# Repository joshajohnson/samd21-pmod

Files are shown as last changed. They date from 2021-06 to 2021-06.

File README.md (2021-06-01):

# Template Hardware Project

## Generate production files
`make`

* generates zipped gerbers, BOM, and iBOM PnP file

## Init Repo
* Due to GitHub template not supporting submodules yet, the below process is required upon first use to configure.
```
git clone git@github.com:joshajohnson/hardware-template.git
mv hardware-template project-name
cd project-name
make init
```

* Configure new git repo

## Begin a new project / board revision
`make new NAME="project-name" VERSION="version" DESIGNER="Your Name"`

* `NAME` is the file name of project and is required, no spaces allowed
* `VERSION` is optional and defaults to `0.1`, must be unique
* `DESIGNER` is optional and defaults to `Josh Johnson`

## Generate gerbers
`make gerb` 

* requires python3 and a small number of dependencies

## Generate BOM
`make bom`

* utilises custom BOM format found in `scripts/josh_bom.py`
* requires dependancy to be installed to global scope `pip3 install kicad_netlist_reader`

## Generate InteractiveHTMLBom
`make pnp`

* requires [InteractiveHTMLBom](https://github.com/openscopeproject/InteractiveHtmlBom) to be installed in `~/local/share/kicad/5.99/scripting/plugins`
* generates ibom according to settings from pcbnew

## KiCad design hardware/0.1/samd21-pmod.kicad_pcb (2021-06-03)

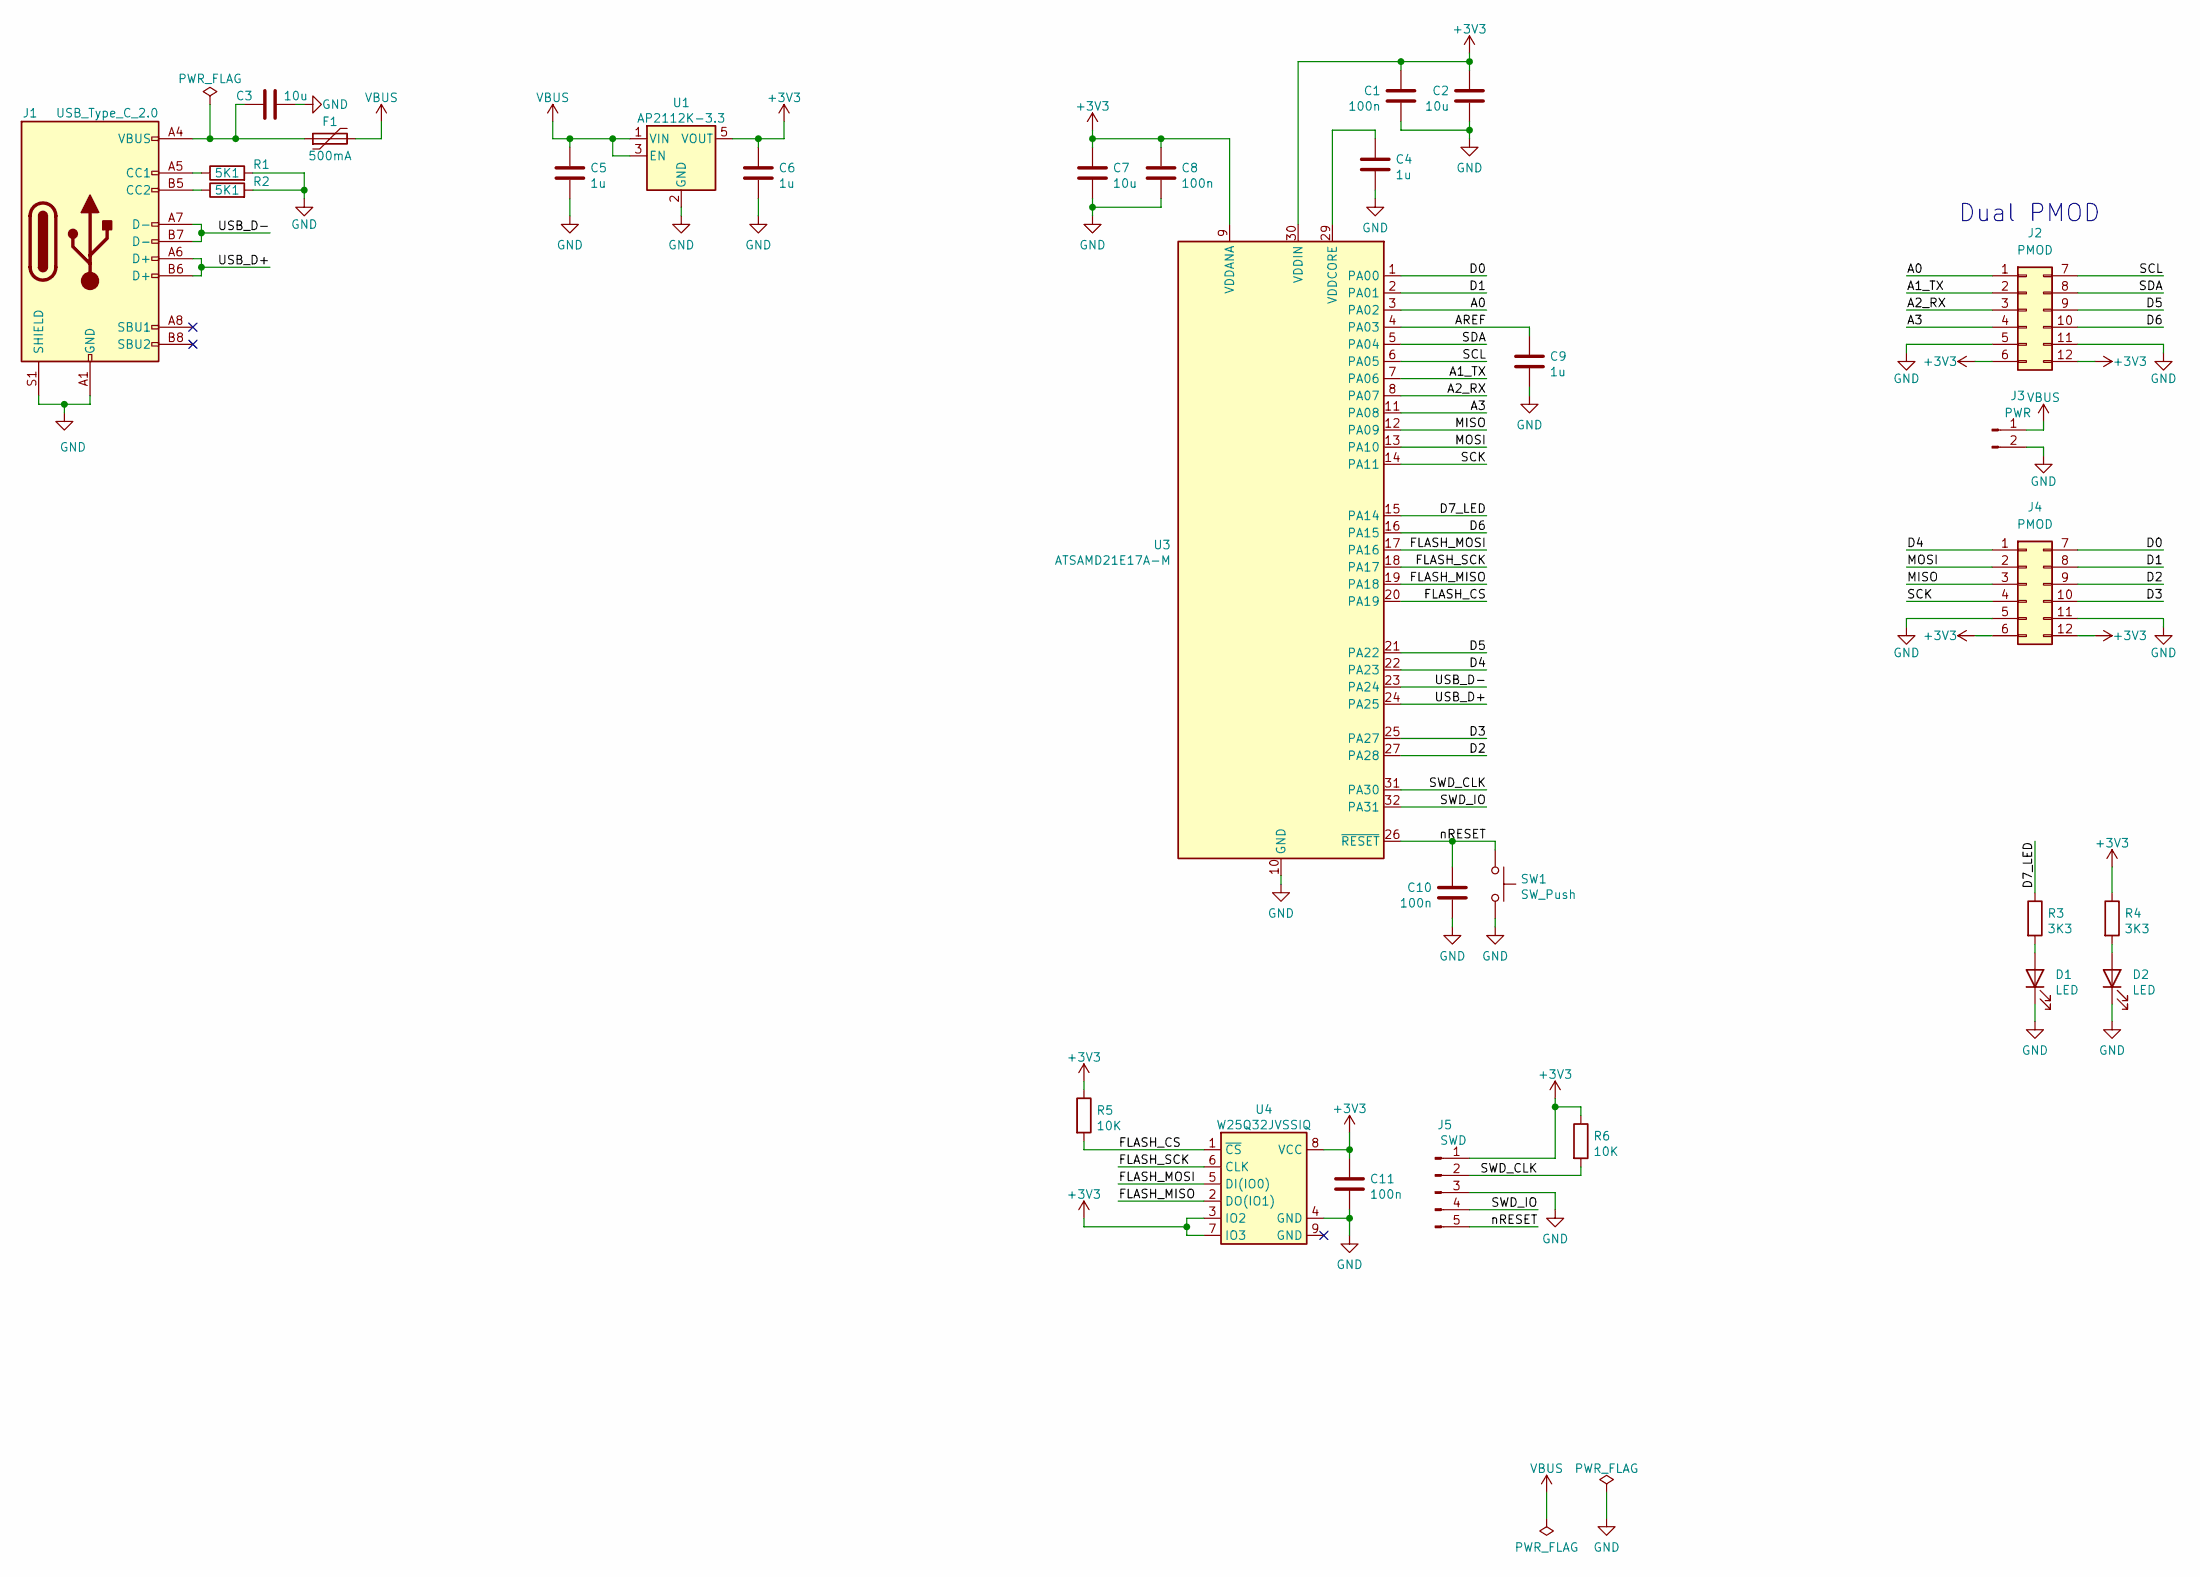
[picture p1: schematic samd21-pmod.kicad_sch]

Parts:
C1, C8, C10, C11: 100n; C_0603_1608Metric
C2, C3, C7: 10u; C_0603_1608Metric
C4, C5, C6, C9: 1u; C_0603_1608Metric
D1, D2: LED; LED_0603_1608Metric
F1: 500mA; Fuse_0603_1608Metric
J1: USB_Type_C_2.0; USB_C_Receptacle_HRO_TYPE-C-31-M-12
J2, J4: PMOD; PMOD_HOST
J3: PWR; PinSocket_1x02_P2.54mm_Vertical
J5: SWD; 5_PIN_THT_Staggered
R1, R2: 5K1; R_0603_1608Metric
R3, R4: 3K3; R_0603_1608Metric
R5, R6: 10K; R_0603_1608Metric
SW1: SW_Push; SW_Push_KMR2
U1: AP2112K-3.3; SOT-23-5
U3: ATSAMD21E17A-M; QFN-32-1EP_5x5mm_P0.5mm_EP3.6x3.6mm
U4: W25Q32JVSSIQ; SOP-8_5.28x5.23mm_P1.27mm

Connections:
+3V3: C1.1, C2.1, C6.1, C7.1, C8.1, C11.1, J2.6, J2.12, J4.6, J4.12, J5.1, R4.1, R5.1, R6.1, U1.5 (VOUT), U3.9 (VDDANA), U3.30 (VDDIN), U4.3 (IO2), U4.7 (IO3), U4.8 (VCC)
/A0: J2.1, U3.3 (PA02)
/A1_TX: J2.2, U3.7 (PA06)
/A2_RX: J2.3, U3.8 (PA07)
/A3: J2.4, U3.11 (PA08)
/AREF: C9.1, U3.4 (PA03)
/D0: J4.7, U3.1 (PA00)
/D1: J4.8, U3.2 (PA01)
/D2: J4.9, U3.27 (PA28)
/D3: J4.10, U3.25 (PA27)
/D4: J4.1, U3.22 (PA23)
/D5: J2.9, U3.21 (PA22)
/D6: J2.10, U3.16 (PA15)
/D7_LED: R3.1, U3.15 (PA14)
/FLASH_CS: R5.2, U3.20 (PA19), U4.1 (~CS)
/FLASH_MISO: U3.19 (PA18), U4.2 (DO(IO1))
/FLASH_MOSI: U3.17 (PA16), U4.5 (DI(IO0))
/FLASH_SCK: U3.18 (PA17), U4.6 (CLK)
/MISO: J4.3, U3.12 (PA09)
/MOSI: J4.2, U3.13 (PA10)
/SCK: J4.4, U3.14 (PA11)
/SCL: J2.7, U3.6 (PA05)
/SDA: J2.8, U3.5 (PA04)
/SWD_CLK: J5.2, R6.2, U3.31 (PA30)
/SWD_IO: J5.4, U3.32 (PA31)
/USB_D+: J1.A6 (D+), J1.B6 (D+), U3.24 (PA25)
/USB_D-: J1.A7 (D-), J1.B7 (D-), U3.23 (PA24)
/nRESET: C10.1, J5.5, SW1.1, U3.26 (~RESET)
GND: C1.2, C2.2, C3.2, C4.2, C5.2, C6.2, C7.2, C8.2, C9.2, C10.2, C11.2, D1.1 (K), D2.1 (K), J1.A1 (GND), J1.A12 (GND), J1.B1 (GND), J1.B12 (GND), J1.S1 (SHIELD), J2.5, J2.11, J3.2, J4.5, J4.11, J5.3, R1.2, R2.2, SW1.2, U1.2 (GND), U3.10 (GND), U3.28 (GND), U3.33 (EP), U4.4 (GND)
unnamed: C4.1, U3.29 (VDDCORE)
unnamed: D1.2 (A), R3.2
unnamed: D2.2 (A), R4.2
unnamed: C3.1, F1.1, J1.A4 (VBUS), J1.A9 (VBUS), J1.B4 (VBUS), J1.B9 (VBUS)
unnamed: J1.A5 (CC1), R1.1
unnamed: J1.B5 (CC2), R2.1
VBUS: C5.1, F1.2, J3.1, U1.1 (VIN), U1.3 (EN)

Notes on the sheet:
Dual PMOD

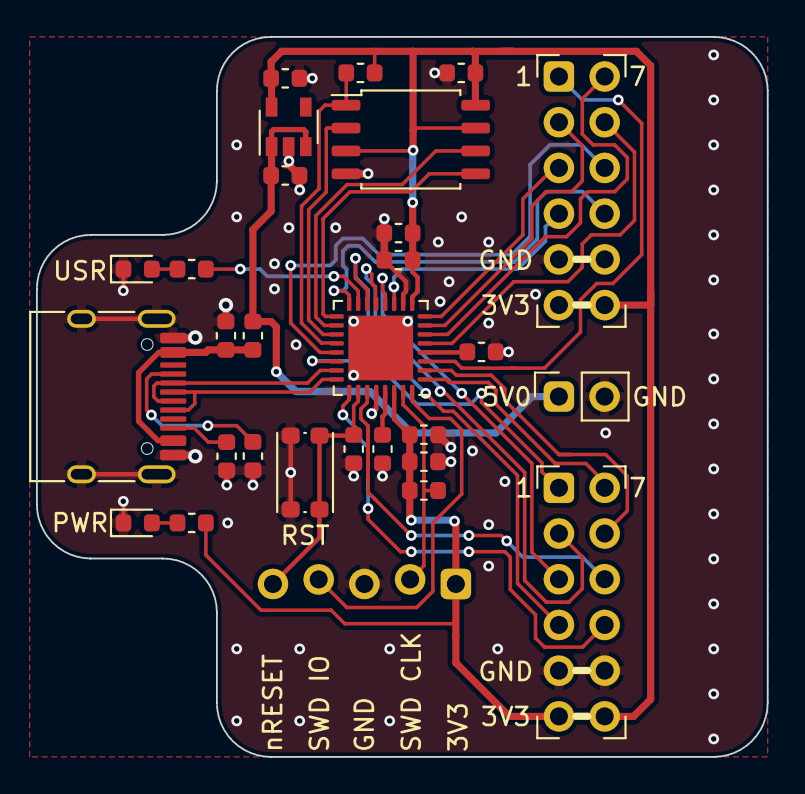
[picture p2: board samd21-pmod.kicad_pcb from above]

Board: 2 copper layers, 40.6 x 40.0 mm, 29 parts (0 on the bottom side), 36 nets.

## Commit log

2021-06-01 initial layout complete
    [samd21-pmod.kicad_pcb, samd21-pmod.kicad_sch]
2021-06-03 tidy up routing
    [samd21-pmod.kicad_pcb, samd21-pmod.kicad_sch]
